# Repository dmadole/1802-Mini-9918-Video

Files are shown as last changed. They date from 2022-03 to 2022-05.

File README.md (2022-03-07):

# 1802-Mini-9918-Video
This is the TMS9XXX video card for the [1802/Mini](https://github.com/dmadole/1802-Mini) system. It supports the following features:

* Supports TMS 9918/9118/9928/9128/9929/9129 video processors
* Composite video with 9X18 or component video with 9X2X
* Outputs video levels for 75-ohm or high-impedance inputs
* Separate negative sync output connector
* Supports group I/O port expansion
* Jumper-selected port address 1/5, 2/6, 3/7, 2/3, 4/5, or 6/7
* Jumper-selected interrupt polling bit on EF1-EF4

Gerber files for the PCBs and PDF schematics can be found in [Releases](https://github.com/dmadole/1802-Mini-9918-Video/releases).

BOMS and any applicable errata or other notes can be found in [notes](https://github.com/dmadole/1802-Mini-9918-Video/tree/main/notes).

For availability of kits and bare PCBs please see http://madole.net/1802/mini/kits

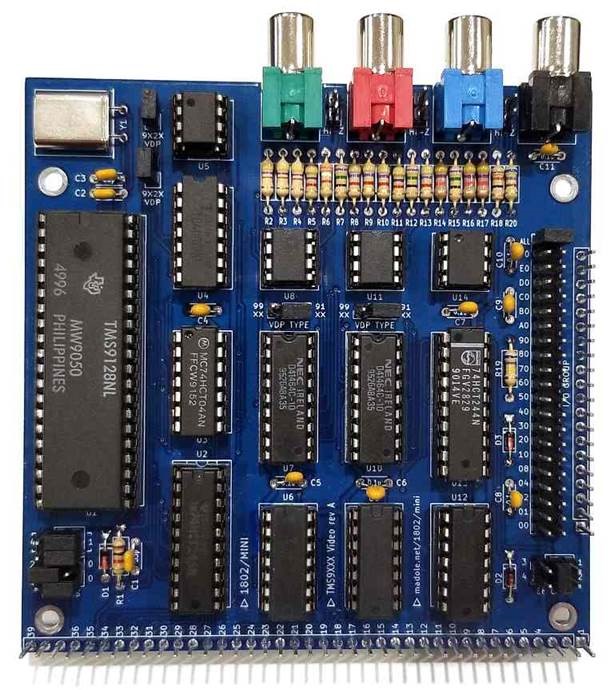
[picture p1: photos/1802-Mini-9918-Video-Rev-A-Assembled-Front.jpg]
1802/Mini 9918 Video Front

 
(Note that this photo is of a revision A board and address jumpers are slightly different than revision B boards. Do not use this photo for reference for jumpers.)

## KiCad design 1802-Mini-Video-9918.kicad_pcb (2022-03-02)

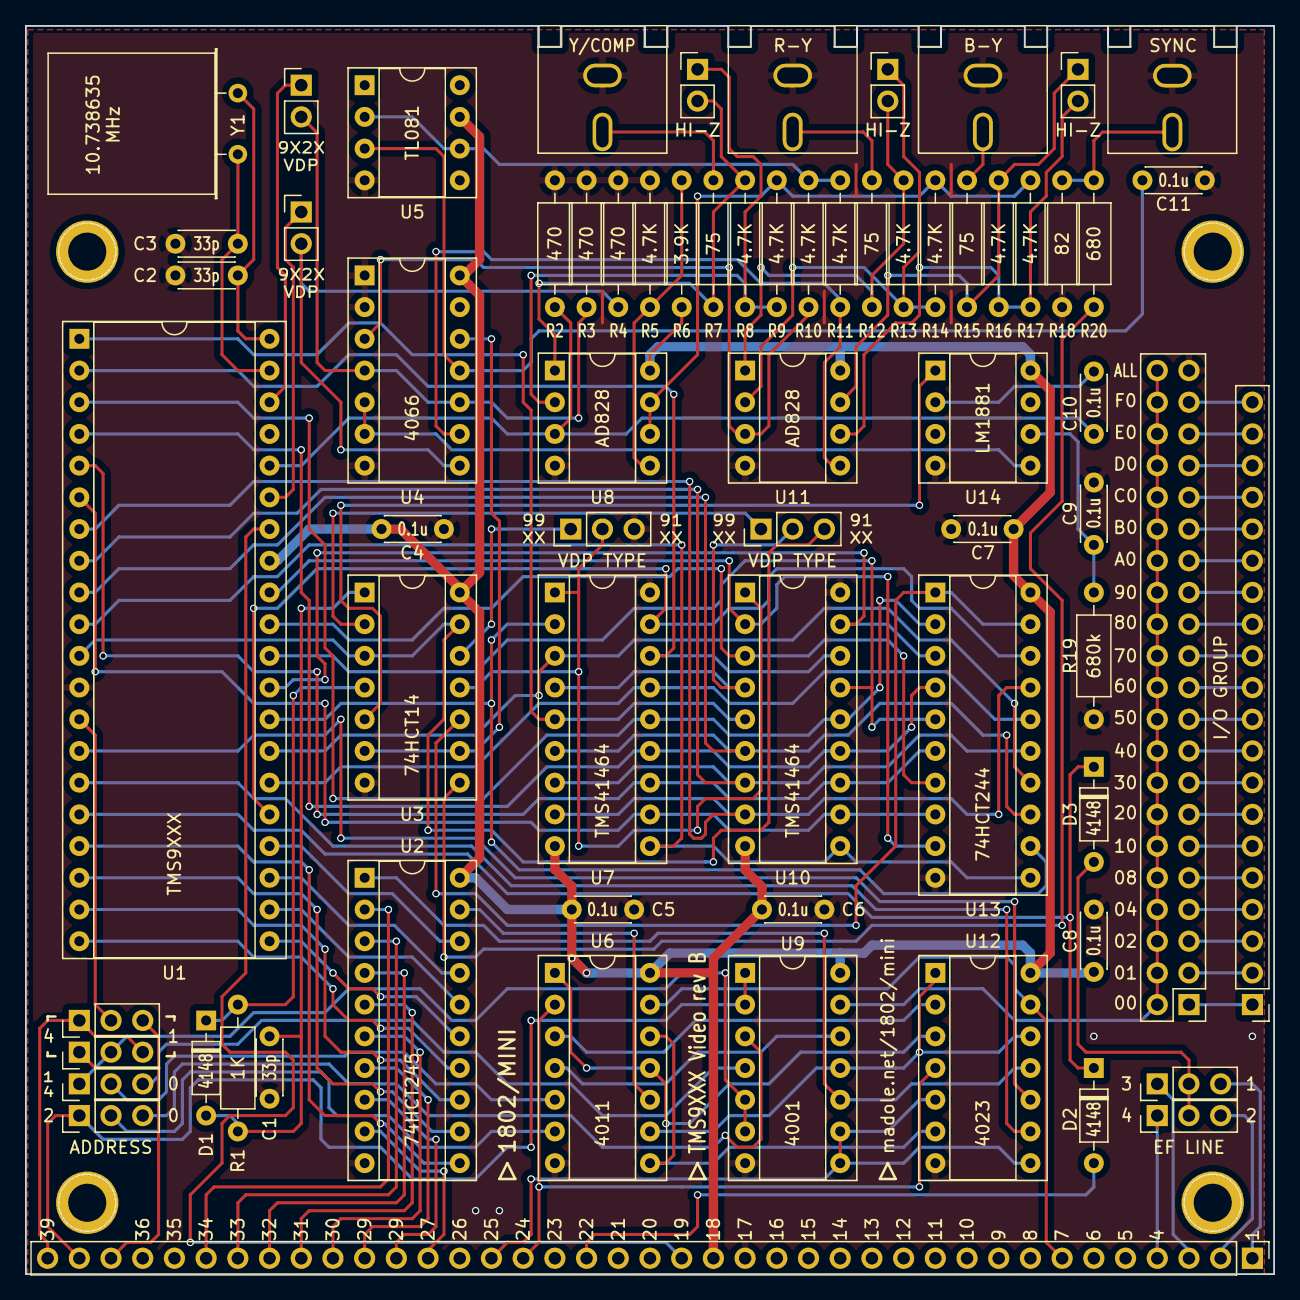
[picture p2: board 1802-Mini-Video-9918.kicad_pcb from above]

Board: 2 copper layers, 100.0 x 100.0 mm, 73 parts (0 on the bottom side), 123 nets.

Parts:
C1, C2, C3: 33p; C_Disc_D4.3mm_W1.9mm_P5.00mm
C4, C5, C6, C7, C8, C9, C10, C11: 0.1u; C_Disc_D4.3mm_W1.9mm_P5.00mm
D1, D2, D3: 4148; D_DO-35_SOD27_P7.62mm_Horizontal
J1: Expansion; PinHeader_1x39_P2.54mm_Vertical
J2: GRP_EXP; PinHeader_1x20_P2.54mm_Vertical
J3: GRP_SEL; PinHeader_2x21_P2.54mm_Vertical
J5: Y/COMP; CUI RCJ-04X
J7: R-Y; CUI RCJ-04X
J9: B-Y; CUI RCJ-04X
J11: SYNC; CUI RCJ-04X
JP1: ADSEL2; PinHeader_1x03_P2.54mm_Vertical
JP2: ADSEL1; PinHeader_1x03_P2.54mm_Vertical
JP3: ADDR1/4; PinHeader_1x03_P2.54mm_Vertical
JP4, JP8, JP9: ADDR2; PinHeader_1x03_P2.54mm_Vertical
JP5, JP6, JP7: HI-Z; PinHeader_1x02_P2.54mm_Vertical
JP10: GSEL; PinHeader_1x03_P2.54mm_Vertical
JP11: WSEL; PinHeader_1x03_P2.54mm_Vertical
JP12, JP13: 9X2X; PinHeader_1x02_P2.54mm_Vertical
P6, P7, P8, P9: CONN_01X01; 1pin
R1: 1K; R_Axial_DIN0207_L6.3mm_D2.5mm_P10.16mm_Horizontal
R2, R3, R4: 470; R_Axial_DIN0207_L6.3mm_D2.5mm_P10.16mm_Horizontal
R5, R8, R9, R10, R11, R13, R14, R16, R17: 4.7K; R_Axial_DIN0207_L6.3mm_D2.5mm_P10.16mm_Horizontal
R6: 3.9K; R_Axial_DIN0207_L6.3mm_D2.5mm_P10.16mm_Horizontal
R7, R12, R15: 75; R_Axial_DIN0207_L6.3mm_D2.5mm_P10.16mm_Horizontal
R18: 82; R_Axial_DIN0207_L6.3mm_D2.5mm_P10.16mm_Horizontal
R19: 680k; R_Axial_DIN0207_L6.3mm_D2.5mm_P10.16mm_Horizontal
R20: 680; R_Axial_DIN0207_L6.3mm_D2.5mm_P10.16mm_Horizontal
U1: TMS9XXX; DIP-40_W15.24mm_Socket
U2: 74HCT245; DIP-20_W7.62mm_Socket
U3: 74HCT14; DIP-14_W7.62mm_Socket
U4: 4066; DIP-14_W7.62mm_Socket
U5: TL081; DIP-8_W7.62mm_Socket
U6: 4011; DIP-14_W7.62mm_Socket
U7, U10: TMS41464; DIP-18_W7.62mm_Socket
U8, U11: AD828; DIP-8_W7.62mm_Socket
U9: 4001; DIP-14_W7.62mm_Socket
U12: 4023; DIP-14_W7.62mm_Socket
U13: 74HCT244; DIP-20_W7.62mm_Socket
U14: LM1881; DIP-8_W7.62mm_Socket
Y1: Crystal; Crystal_HC49-U_Horizontal

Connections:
/AD0: U1.10, U7.10, U10.10, U13.11
/AD1: U1.9, U7.6, U10.6, U13.13
/AD2: U1.8, U7.7, U10.7, U13.15
/AD3: U1.7, U7.8, U10.8, U13.17
/AD4: U1.6, U7.11, U10.11, U13.8
/AD5: U1.5, U7.12, U10.12, U13.6
/AD6: U1.4, U7.13, U10.13, U13.4
/AD7: U1.3, U7.14, U10.14, U13.2
/BUS0: J1.27, U2.9
/BUS1: J1.28, U2.8
/BUS2: J1.29, U2.7
/BUS3: J1.30, U2.6
/BUS4: J1.31, U2.5
/BUS5: J1.32, U2.4
/BUS6: J1.33, U2.3
/BUS7: J1.34, U2.2
/RD0: U1.32, U10.2, U13.9
/RD1: U1.31, U10.3, U13.7
/RD2: U1.30, U10.15, U13.5
/RD3: U1.29, U10.17, U13.3
/RD4: U1.28, U7.2, U13.12
/RD5: U1.27, U7.3, U13.14
/RD6: U1.26, U7.15, U13.16
/RD7: U1.25, U7.17, U13.18
GND: C1.2, C2.2, C3.2, C4.1, C5.1, C6.1, C7.1, C8.1, C9.2, C11.1, J1.17, J3.41, J5.2, J7.2, J9.2, J11.2, JP10.3, R2.2, R3.2, R4.2, R5.2, R18.2, R19.1, U1.12, U2.10, U3.7, U4.1, U4.2, U4.7, U4.13, U5.4, U6.7, U7.18, U8.4, U9.7, U10.18, U11.4, U12.7, U13.10, U14.4
N0: J1.39, JP1.1, JP2.3
N1: J1.38, JP4.1, U9.1, U9.2
N2: J1.37, JP1.3, JP2.1
unnamed: C1.1, D1.2, R1.1, U3.1
unnamed: C2.1, U1.40, Y1.1
unnamed: C3.1, U1.39, Y1.2
unnamed: C9.1, R19.2, U14.6
unnamed: C10.1, R2.1, U1.36, U8.3
unnamed: C10.2, U14.2
unnamed: C11.2, U4.11, U5.3
unnamed: D1.1, R1.2, U3.4
unnamed: D2.1, D3.1, U1.16
unnamed: D3.2, JP8.2, JP9.2
unnamed: J2.1, J3.1
unnamed: J2.2, J3.3
unnamed: J2.3, J3.5
unnamed: J2.4, J3.7
unnamed: J2.5, J3.9
unnamed: J2.6, J3.11
unnamed: J2.7, J3.13
unnamed: J2.8, J3.15
unnamed: J2.9, J3.17
unnamed: J2.10, J3.19
unnamed: J2.11, J3.21
unnamed: J2.12, J3.23
unnamed: J2.13, J3.25
unnamed: J2.14, J3.27
unnamed: J2.15, J3.29
unnamed: J2.16, J3.31
unnamed: J2.17, J3.33
unnamed: J2.18, J3.35
unnamed: J2.19, J3.37
unnamed: J2.20, J3.39
unnamed: J5.1, R7.2
unnamed: J7.1, R12.2
unnamed: J9.1, R15.2
unnamed: J11.1, R18.1, R20.2
unnamed: JP1.2, U1.13
unnamed: JP2.2, JP3.1, U9.5, U9.6
unnamed: JP3.2, U6.5
unnamed: JP3.3, U9.4
unnamed: JP4.2, U6.6
unnamed: JP4.3, U9.3
unnamed: JP5.1, R8.1, R9.1, U8.2
unnamed: JP5.2, R7.1, R8.2, U8.1
unnamed: JP6.1, R13.1, R14.1, U11.2
unnamed: JP6.2, R12.1, R13.2, U11.1
unnamed: JP7.1, R15.1, R16.2, U11.7
unnamed: JP7.2, R16.1, R17.1, U11.6
unnamed: JP10.1, U3.12
unnamed: JP10.2, U3.11, U7.1, U10.1
unnamed: JP11.1, U3.2
unnamed: JP11.2, U7.4, U10.4
unnamed: JP11.3, U1.11, U3.3, U3.13
unnamed: JP12.1, U1.35
unnamed: JP12.2, R4.1, U4.8
unnamed: JP13.1, U1.38
unnamed: JP13.2, R3.1, U4.4, U4.10
unnamed: R5.1, R6.2, U8.5
unnamed: R10.1, U4.3, U11.3
unnamed: R10.2, R11.2, U5.2, U5.6
unnamed: R11.1, U4.9, U11.5
unnamed: R9.2, R14.2, R17.2, U8.6, U8.7
unnamed: R20.1, U3.8
unnamed: U1.1, U7.5, U10.5
unnamed: U1.2, U7.16, U10.16
unnamed: U1.14, U12.10
unnamed: U1.15, U12.9
unnamed: U1.17, U2.11
unnamed: U1.18, U2.12
unnamed: U1.19, U2.13
unnamed: U1.20, U2.14
unnamed: U1.21, U2.15
unnamed: U1.22, U2.16
unnamed: U1.23, U2.17
unnamed: U1.24, U2.18
unnamed: U2.19, U6.10
unnamed: U3.6, U3.9, U4.12
unnamed: U6.4, U9.12
unnamed: U6.9, U9.11, U12.1, U12.12
unnamed: U6.3, U12.2
unnamed: U6.1, U6.11, U12.3
unnamed: U6.8, U6.12, U12.6
unnamed: U2.1, U9.10, U12.11
unnamed: U3.10, U13.1, U13.19
unnamed: U3.5, U14.1
unnamed: U4.5, U4.6, U14.5
TPB: J1.7, U6.13, U12.13
VCC: C4.2, C5.2, C6.2, C7.2, C8.2, J1.18, R6.1, U1.33, U2.20, U3.14, U4.14, U5.7, U6.14, U7.9, U8.8, U9.14, U10.9, U11.8, U12.14, U13.20, U14.8
~CLEAR: J1.19, U1.34
~EF1: J1.1, JP8.3
~EF2: J1.2, JP9.3
~EF3: J1.3, JP8.1
~EF4: J1.4, JP9.1
~GROUP: J3.2, J3.4, J3.6, J3.8, J3.10, J3.12, J3.14, J3.16, J3.18, J3.20, J3.22, J3.24, J3.26, J3.28, J3.30, J3.32, J3.34, J3.36, J3.38, J3.40, J3.42, U9.13
~INT: D2.2, J1.22
~MRD: J1.25, U9.8, U9.9, U12.5, U12.8
~MWR: J1.24, U6.2, U12.4

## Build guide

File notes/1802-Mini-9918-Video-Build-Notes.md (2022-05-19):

# 1802/Mini 9918 Video Assembly Notes

Follow usual assembly practices, which I will not document here. I recommend installing the lowest-height components first (resistors, diodes, right-angle connectors), then the next higher (sockets), and so on.

Please review all jumper settings before trying to operate the board. In particular, a group select jumper must be installed for the board to work, in systems without group I/O capability, this should be on the ALL position.

## Capacitor Values

Note that there are two different values of ceramic capacitor on this board, 33pF and 0.1uF. Please be sure to install the correct value in the correct location. The 33pF are typically marked "33J" and go at C1-3, and the 0.1uF are typically marked "104" and go at C4-10.

## Video Output Connectors

The RCA jacks should be installed flush to the board, with the plastic posts fitting into the notches at the edge of the board. When soldering, the connectors should be pressed firmly down toward the board and inward toward the center of the board. This will ensure the posts are firm against the board to provide maximum physical support of the connectors.

Recommended jack colors are yellow in the Y/COMP position for component video-only boards, and for composite video boards, green at Y/COM, red at R-Y, blue at B-Y, and black at SYNC.

## VDP Type Jumpers

The two jumpers marked 9X2X VDP, should be installed when using a VDP chip with component (Y/R-Y/B-Y) output (9928/9128/9929/9129) and removed when using a VDP chip with composite output (9918/9118).

The two jumpers marked VDP TYPE should be installed on the 99XX side when using 9918/9928/9929 VDP chips, or on the 91XX side when using 9118/9128/9129 VDP chips.

## Addressing

The video interface occupies two I/O ports which are set by the address jumpers. The standard configuration is for addresses 1 and 5 which are selected by setting  the two 4-1 jumpers to 1, the 1/4-0 jumper to 1/4, and the 2-0 jumper to 0. Here are all the address options:

| Ports | 4-1 | 1/4-0 | 2-0 |
|:-----:|:---:|:-----:|:---:|
| 1 & 5 |  1  |  1/4  |  0  |
| 2 & 3 |  4  | 0 |  2  |
| 2 & 6 |  1  | 0 |  2  |
| 3 & 7 |  1  |  1/4  |  2  |
| 4 & 5 |  4  |  1/4  |  0  |
| 6 & 7 |  4  |  1/4  |  2  |

Two-level I/O group selection is also supported, if the systemn contains a group expander board, in which case the desired group address should be jumpered on the I/O group jumpers. If no group expander board is installed, then the jumper should be installed on the ALL setting.

## EF Lines

The VDP interrupt signal, gated with the group-select signal, can be connected to any of the EF flag inputs using the EF LINE jumpers. This may be useful for custom polling drivers, or to support faster polling of interrupt-driven devices to determine which needs service. Unless VDP software is being used which monitors an EF line, it is recommended to leave this jumper off.
